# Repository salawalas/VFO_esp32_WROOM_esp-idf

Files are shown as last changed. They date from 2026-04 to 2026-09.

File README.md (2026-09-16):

# ESP32 VFO z generatorem Si5351A

Sterownik VFO zbudowany na ESP32-WROOM-32 i syntezerze Si5351A. Projekt generuje przestrajany sygnal w zakresie od 100 kHz do 225 MHz, pokazuje czestotliwosc na kolorowym wyswietlaczu TFT oraz udostepnia wygodna obsluge przez enkoder i piec przyciskow.

Repozytorium zawiera firmware ESP-IDF/PlatformIO oraz projekt PCB i schemat w KiCad.

## Najwazniejsze funkcje

- Zakres VFO: `100 kHz .. 225 MHz`.
- Syntezer Si5351A sterowany przez I2C 400 kHz.
- Wyjscia Si5351:
  - `CLK0` - glowny sygnal LO/VFO,
  - `CLK1` - nosna I,
  - `CLK2` - nosna Q, przesunieta wzgledem I.
- Kolorowy wyswietlacz ST7735 1.8", framebuffer `160 x 128 px`.
- Analogowa tarcza VFO oraz cyfrowy odczyt czestotliwosci.
- Enkoder kwadraturowy PCNT z dynamicznym przyspieszaniem strojenia.
- Kroki strojenia: `10 Hz`, `100 Hz`, `1 kHz`, `10 kHz`, `100 kHz`, `1 MHz`.
- Dziesiec komorek pamieci `M0..M9`.
- Autozapis ostatniej czestotliwosci do NVS po okresie bezczynnosci.
- Menu pasm z gotowymi czestotliwosciami startowymi.
- Blokada strojenia `LOCK`.
- Kalibracja czestotliwosci kwarcu Si5351 w zakresie `-5000..+5000 Hz`.
- Regulacja jasnosci podswietlenia PWM.
- Oddzielne srodowiska PlatformIO: `esp32_release` i `esp32_debug`.

## Sprzet

Glownymi elementami ukladu sa:

- ESP32-WROOM-32,
- modul Si5351A,
- wyswietlacz TFT 1.8" ze sterownikiem ST7735,
- enkoder obrotowy z przyciskiem,
- 5 przyciskow tact switch,
- podswietlenie wyswietlacza sterowane PWM,
- plytka PCB zaprojektowana w KiCad.

Pliki KiCad sa w katalogu `Kicad files/`.

## Polaczenia GPIO

| Funkcja | GPIO |
| --- | ---: |
| Enkoder A | 17 |
| Enkoder B | 16 |
| Przycisk enkodera SW | 34 |
| STEP_DN | 26 |
| STEP_UP | 27 |
| MEM | 25 |
| SAVE | 32 |
| BAND | 33 |
| Si5351 SDA | 21 |
| Si5351 SCL | 22 |
| ST7735 SCLK | 18 |
| ST7735 MOSI | 23 |
| ST7735 CS | 5 |
| ST7735 DC | 2 |
| ST7735 RST | 15 |
| Podswietlenie TFT | 4 |

Przyciski sa aktywne stanem niskim. W tej konstrukcji zewnetrzne rezystory pull-up sa wymagane dla GPIO16, GPIO17, GPIO33 i GPIO34. Na plytce zastosowano 4.7 kOhm, ale praktyczny zakres to ok. 2.2 kOhm .. 10 kOhm.

## Ekran

Normalny widok VFO pokazuje:

- analogowa tarcze strojenia,
- cyfrowa czestotliwosc generowana,
- aktywny krok strojenia,
- aktywny bank pamieci `VFO` albo `M1..M9`,
- graficzne overlaye dla operacji `SAVE`, `LOAD`, `LOCK`, menu pasm, jasnosci i kalibracji.

W trybie `LOCK` czestotliwosc pozostaje widoczna, a na ekranie pojawia sie duzy symbol klodki oraz napis `LOCK` na dole.

## Obsluga

### Enkoder

| Akcja | Efekt |
| --- | --- |
| Obrot w trybie VFO | Zmiana czestotliwosci wedlug aktywnego kroku |
| Szybki obrot | Automatyczne przyspieszenie strojenia `x10`, `x100`, `x1000` |
| Krotkie nacisniecie SW | Otwarcie menu pasm lub zatwierdzenie wyboru pasma |
| Dlugie nacisniecie SW | Zmiana kierunku pracy enkodera |
| Obrot w menu BAND | Przewijanie listy pasm |
| Obrot w XTAL CAL | Zmiana korekty kwarcu |
| Obrot w BRIGHTNESS | Zmiana jasnosci podswietlenia |

### Przyciski

| Przycisk | Krotkie nacisniecie | Dlugie nacisniecie |
| --- | --- | --- |
| STEP_DN | Mniejszy krok strojenia | - |
| STEP_UP | Wiekszy krok strojenia | - |
| MEM | Nastepny bank pamieci / YES w dialogu / SAVE w ekranach ustawien | Wczytanie czestotliwosci z aktywnego banku |
| SAVE | NO/CANCEL w dialogach | Otwarcie dialogu zapisu do aktywnego banku |
| BAND | Ekran regulacji jasnosci | Kalibracja kwarcu XTAL |
| STEP_DN + STEP_UP | `LOCK` po przytrzymaniu ok. 1 s | `LOCK` po przytrzymaniu ok. 1 s |

W trybie `LOCK` zmiana czestotliwosci i kroku jest blokowana. Odblokowanie odbywa sie ta sama kombinacja `STEP_DN + STEP_UP`.

## Pamiec i pasma

Firmware przechowuje parametry w NVS:

- ostatnia czestotliwosc,
- 10 komorek pamieci `M0..M9`,
- ostatni krok strojenia,
- korekta kwarcu Si5351,
- jasnosc wyswietlacza,
- ostatnio uzywany bank.

Domyslne komorki pamieci:

| Bank | Czestotliwosc |
| --- | ---: |
| M0 | 14.230 MHz |
| M1 | 3.730 MHz |
| M2 | 3.8531 MHz |
| M3 | 5.450 MHz |
| M4 | 5.505 MHz |
| M5 | 6.070 MHz |
| M6 | 7.130 MHz |
| M7 | 7.8781 MHz |
| M8 | 8.957 MHz |
| M9 | 10.100 MHz |

Menu pasm zawiera:

`30m`, `20m`, `17m`, `15m`, `12m`, `10m`, `6m` oraz `FM 100 MHz`.

## Tryby ekranowe

- `VFO` - normalna praca i strojenie.
- `SAVE TO Mx?` - potwierdzenie zapisu aktualnej czestotliwosci do pamieci.
- `SAVED` - komunikat po zapisie.
- `LOAD` - komunikat po wczytaniu pamieci.
- `SELECT BAND` - wybor pasma lub preset FM.
- `BRIGHTNESS` - regulacja jasnosci podswietlenia.
- `XTAL CALIBRATION` - korekta czestotliwosci referencyjnej Si5351.
- `LOCK` - blokada przypadkowej zmiany czestotliwosci.

## Budowanie

Projekt jest przygotowany pod PlatformIO z frameworkiem ESP-IDF.

Domyslnym srodowiskiem jest release:

```powershell
pio run
```

Jawny build release:

```powershell
pio run -e esp32_release
```

Build debug:

```powershell
pio run -e esp32_debug
```

Wgrywanie:

```powershell
pio run -e esp32_release -t upload
```

Monitor portu szeregowego:

```powershell
pio device monitor
```

Domyslny port uploadu w `platformio.ini` to `COM42`.

## Konfiguracja buildow

`platformio.ini` definiuje dwa warianty:

- `esp32_release` - normalny build firmware,
- `esp32_debug` - build debug z wyzszym poziomem logow.

Wspolne ustawienia ESP-IDF sa w `sdkconfig.defaults`. Dodatkowe ustawienia debug sa w `sdkconfig.debug.defaults`. Pelne pliki `sdkconfig.esp32_*` sa generowane przez PlatformIO lokalnie i sa ignorowane przez git.

## Struktura projektu

| Sciezka | Opis |
| --- | --- |
| `src/main.c` | Inicjalizacja systemu, zadanie wyswietlacza |
| `src/si5351.c` | Sterownik i obliczenia rejestrow Si5351 |
| `src/display.c` | Sterownik ST7735 i transfer DMA |
| `src/graph.c` | Framebuffer RGB i prymitywy graficzne |
| `src/dial.c` | Analogowa tarcza VFO |
| `src/encoder.c` | Obsluga enkodera PCNT |
| `src/buttons.c` | Obsluga przyciskow i trybow |
| `src/nvs_storage.c` | Pamiec NVS i autozapis |
| `src/ui_overlay.c` | Overlaye graficzne i menu |
| `include/config.h` | Glowne stale konfiguracyjne |
| `Kicad files/` | Projekt PCB i schemat |

## Uwagi

Projekt jest przeznaczony do pracy jako eksperymentalny generator/VFO. Przy podlaczaniu do torow radiowych nalezy zadbac o odpowiednie poziomy sygnalu, filtracje harmonicznych, ekranowanie i zgodnosc z lokalnymi przepisami dotyczacymi emisji radiowych.

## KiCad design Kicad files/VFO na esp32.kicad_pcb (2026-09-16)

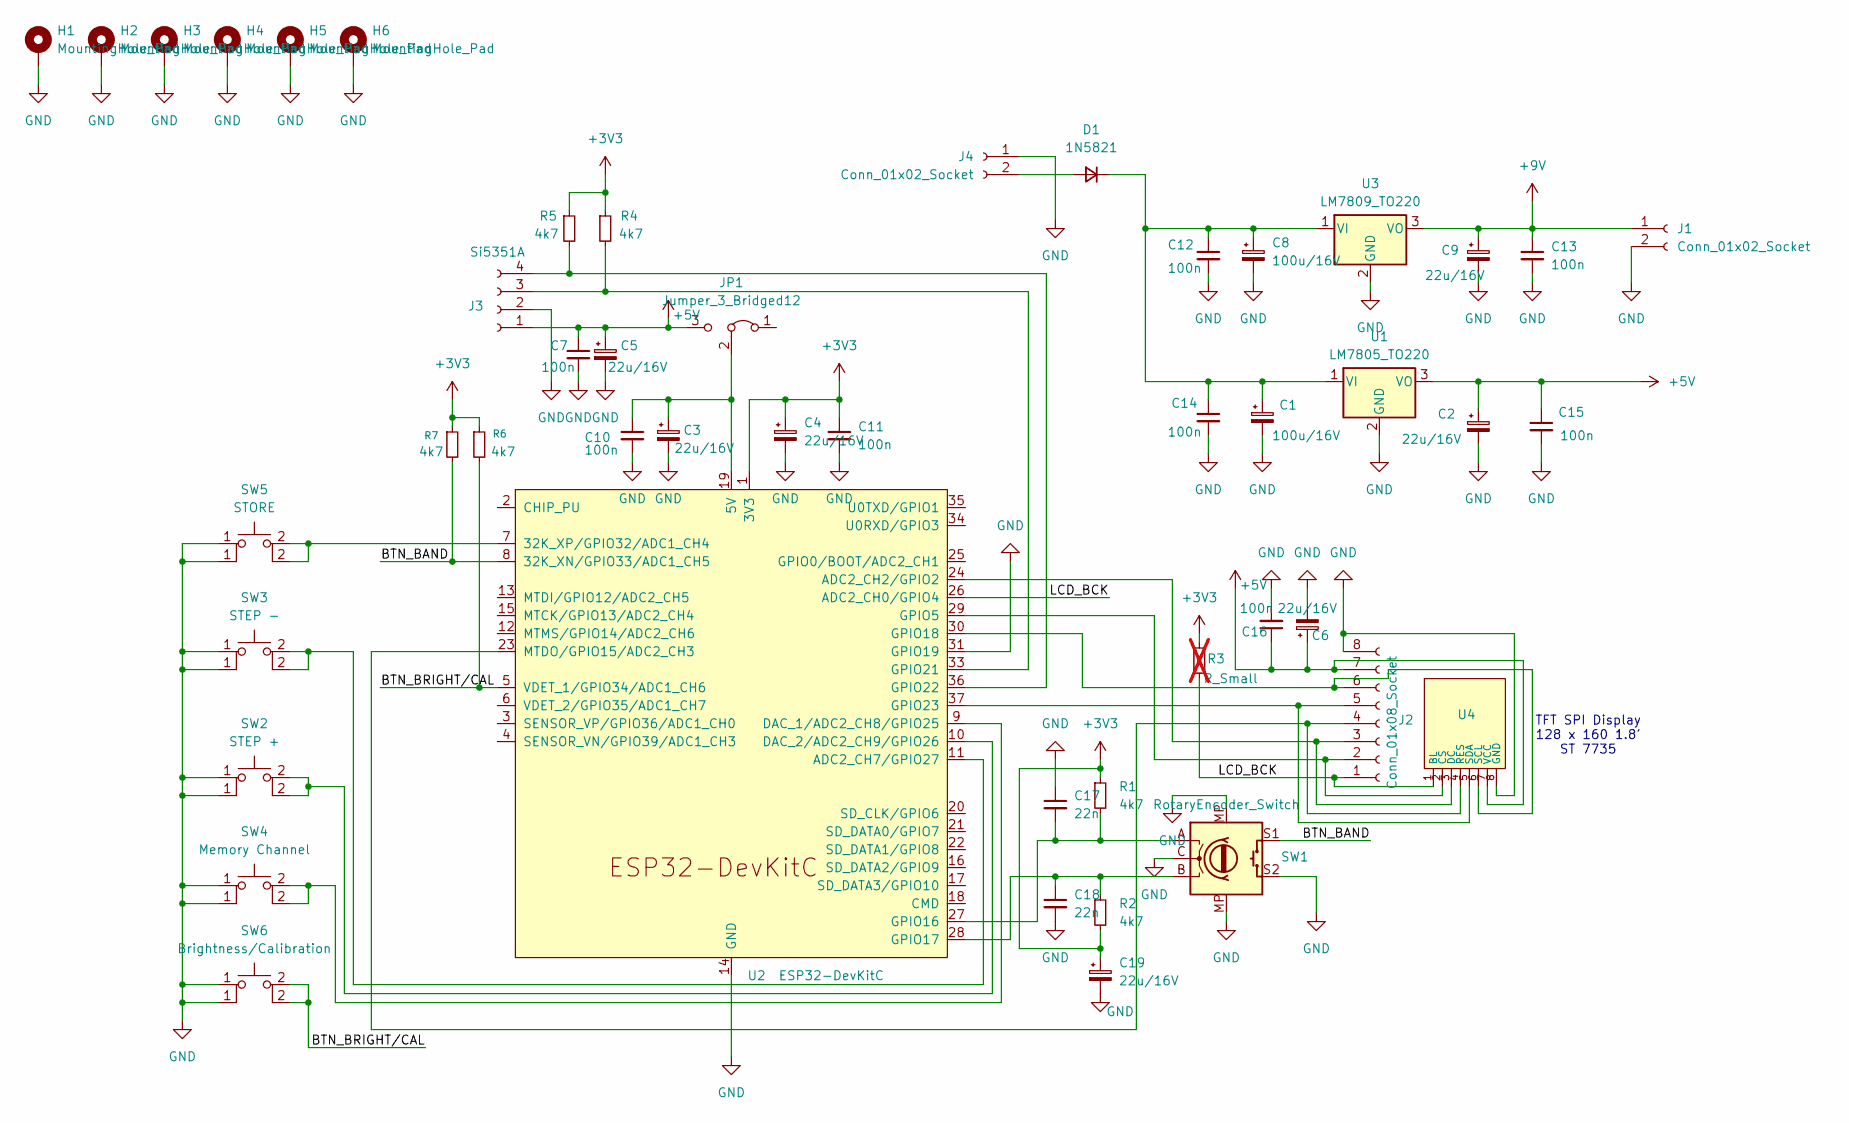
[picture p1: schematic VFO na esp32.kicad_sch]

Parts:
C1, C8: 100u/16V; CP_Radial_D8.0mm_P3.50mm
C2, C3, C4, C5, C6, C9, C19: 22u/16V; CP_Radial_Tantal_D5.0mm_P5.00mm
C7, C10, C11, C12, C13, C14, C15, C16: 100n; C_0805_2012Metric_Pad1.18x1.45mm_HandSolder
C17, C18: 22n; C_Axial_L5.1mm_D3.1mm_P10.00mm_Horizontal
D1: 1N5821; D_DO-15_P10.16mm_Horizontal
H1, H2, H3, H4, H5, H6: MountingHole_Pad; MountingHole_2.7mm_M2.5_DIN965_Pad_TopBottom
J1, J4: Conn_01x02_Socket; JST_EH_S2B-EH_1x02_P2.50mm_Horizontal
J2: Conn_01x08_Socket; PinSocket_1x08_P2.54mm_Vertical
J3: Si5351A; JST_PH_B4B-PH-K_1x04_P2.00mm_Vertical
JP1: Jumper_3_Bridged12; PinHeader_1x03_P2.54mm_Vertical
R1, R2: 4k7; R_Axial_DIN0207_L6.3mm_D2.5mm_P10.16mm_Horizontal
R3: R_Small; R_Axial_DIN0207_L6.3mm_D2.5mm_P10.16mm_Horizontal; not fitted
R4, R5: 4k7; R_0805_2012Metric_Pad1.20x1.40mm_HandSolder
R6, R7: 4k7; R_1206_3216Metric
SW1: RotaryEncoder_Switch; RotaryEncoder_Alps_EC11E-Switch_Vertical_H20mm
SW2: STEP +; SW_PUSH_6mm_H5mm
SW3: STEP -; SW_PUSH_6mm_H5mm
SW4: Memory Channel; SW_PUSH_6mm_H5mm
SW5: STORE; SW_PUSH_6mm_H5mm
SW6: Brightness/Calibration; SW_PUSH_6mm_H5mm
U1: LM7805_TO220; TO-220F-3_Horizontal_TabDown
U2: ESP32-DevKitC
U3: LM7809_TO220; TO-220F-3_Horizontal_TabDown
U4: TFT_SPI_1.8inch_128x160

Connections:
+3V3: C4.1, C11.1, C19.1, R1.1, R2.2, R3.2, R4.1, R5.1, R6.1, R7.1, U2.1 (3V3)
+5V: C2.1, C5.1, C6.1, C7.1, C15.1, C16.1, J2.7, J3.1, JP1.3 (B), U1.3 (VO), U4.7 (VCC)
+9V: C9.1, C13.1, J1.1, U3.3 (VO)
/BTN_BAND: R7.2, SW1.S1, U2.8 (32K_XN/GPIO33/ADC1_CH5)
/BTN_BRIGHT/CAL: R6.2, SW6.2, U2.5 (VDET_1/GPIO34/ADC1_CH6)
/LCD_BCK: J2.1, R3.1, U2.26 (ADC2_CH0/GPIO4), U4.1 (BL)
GND: C1.2, C2.2, C3.2, C4.2, C5.2, C6.2, C7.2, C8.2, C9.2, C10.2, C11.2, C12.2, C13.2, C14.2, C15.2, C16.2, C17.1, C18.2, C19.2, H1.1 (1_1), H2.1 (1_1), H3.1 (1_1), H4.1 (1_1), H5.1 (1_1), H6.1 (1_1), J1.2, J2.8, J3.2, J4.1, SW1.C, SW1.MP, SW1.S2, SW2.1, SW3.1, SW4.1, SW5.1, SW6.1, U1.2 (GND), U2.14 (GND), U2.31 (GPIO19), U2.32 (GND), U2.38 (GND), U3.2 (GND), U4.8 (GND)
unnamed: D1.2 (A), J4.2
unnamed: C1.1, C8.1, C12.1, C14.1, D1.1 (K), U1.1 (VI), U3.1 (VI)
unnamed: J2.2, U2.29 (GPIO5), U4.2 (CS)
unnamed: J2.3, U2.24 (ADC2_CH2/GPIO2), U4.3 (DC)
unnamed: J2.4, U2.23 (MTDO/GPIO15/ADC2_CH3), U4.4 (RES)
unnamed: J2.5, U2.37 (GPIO23), U4.5 (SDA)
unnamed: J2.6, U2.30 (GPIO18), U4.6 (SCL)
unnamed: J3.3, R4.2, U2.33 (GPIO21)
unnamed: J3.4, R5.2, U2.36 (GPIO22)
unnamed: C3.1, C10.1, JP1.2 (C), U2.19 (5V)
unnamed: SW5.2, U2.7 (32K_XP/GPIO32/ADC1_CH4)
unnamed: SW3.2, U2.11 (ADC2_CH7/GPIO27)
unnamed: SW4.2, U2.9 (DAC_1/ADC2_CH8/GPIO25)
unnamed: SW2.2, U2.10 (DAC_2/ADC2_CH9/GPIO26)
unnamed: C17.2, R1.2, SW1.A, U2.27 (GPIO16)
unnamed: C18.1, R2.1, SW1.B, U2.28 (GPIO17)

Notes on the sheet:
TFT SPI Display 128 x 160 1.8' ST 7735

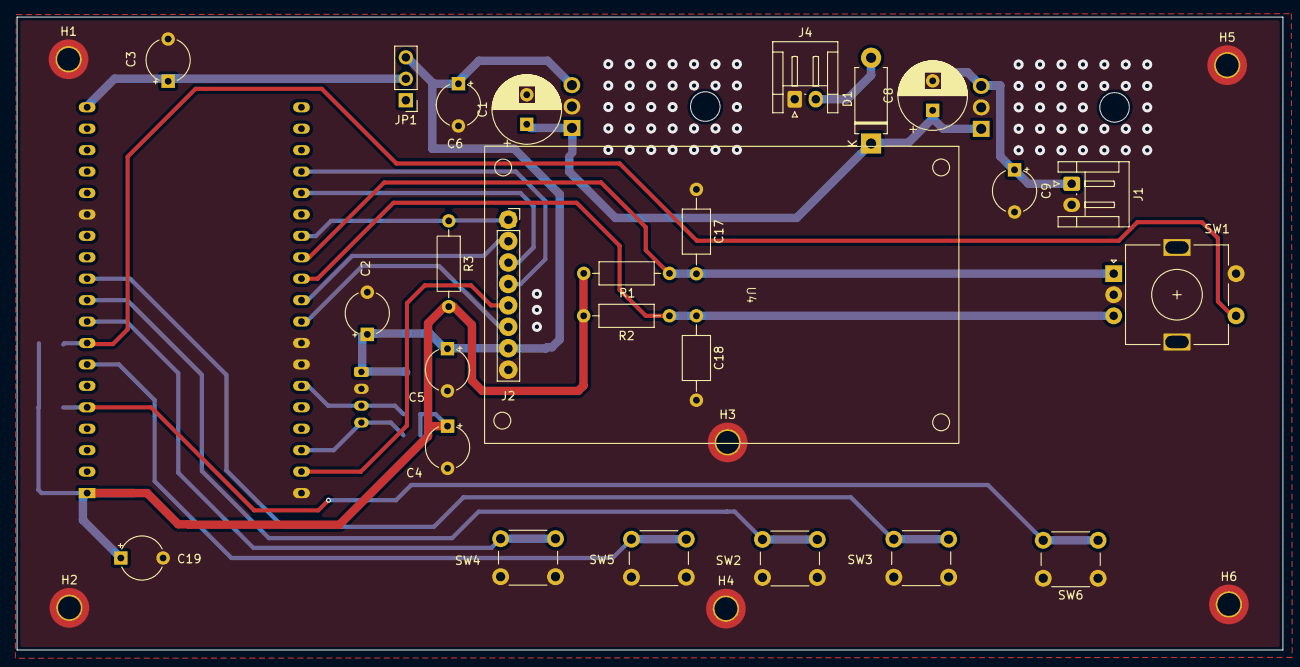
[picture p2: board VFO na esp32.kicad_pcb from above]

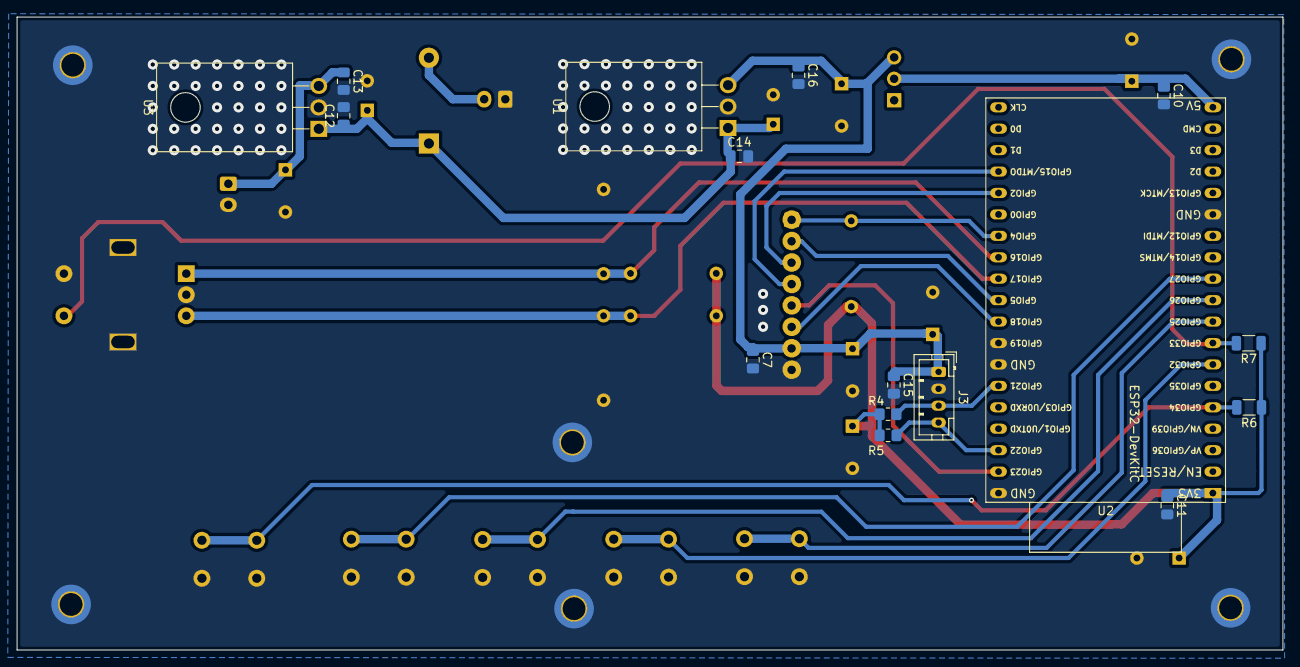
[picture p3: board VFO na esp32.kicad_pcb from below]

Board: 2 copper layers, 150.0 x 75.0 mm, 48 parts (16 on the bottom side), 23 nets.

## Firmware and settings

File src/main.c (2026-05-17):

/*===========================================================================
 *  main.c — VFO Controller (ESP-IDF 5.x / PlatformIO)
 *===========================================================================*/
#include <stdio.h>
#include <string.h>

#include "freertos/FreeRTOS.h"
#include "freertos/task.h"
#include "freertos/semphr.h"

#include "esp_log.h"
#include "esp_err.h"
#include "nvs_flash.h"
#include "driver/ledc.h"

#include "config.h"
#include "vfo_state.h"
#include "si5351.h"
#include "display.h"
#include "graph.h"
#include "dial.h"
#include "encoder.h"
#include "buttons.h"
#include "nvs_storage.h"
#include "ui_overlay.h"
#include "version.h"
#include "esp_system.h"
#include "esp_chip_info.h"
#include "esp_flash.h"

static void display_task(void *arg);
static void system_init(void);
static void tasks_start(void);
static void backlight_init(uint8_t pct);

/*===========================================================================
 *  app_main
 *===========================================================================*/
void app_main(void)
{
    ESP_LOGI(TAG_MAIN, "============================================");
    //ESP_LOGI(TAG_MAIN, "  %s  %s", FW_NAME, FW_VERSION);
    //ESP_LOGI(TAG_MAIN, "  %s", FW_AUTHOR);
    //ESP_LOGI(TAG_MAIN, "============================================");

    ESP_LOGI(TAG_MAIN, "%s %s", FW_NAME, FW_VERSION);
    ESP_LOGI(TAG_MAIN, "%s", FW_AUTHOR);
    ESP_LOGI(TAG_MAIN, "%s", BUILD_DATE);
    ESP_LOGI(TAG_MAIN, "commit %s", FW_COMMIT);
    ESP_LOGI(TAG_MAIN, "============================================");

    /* NVS flash init */
    esp_err_t ret = nvs_flash_init();
    if (ret == ESP_ERR_NVS_NO_FREE_PAGES ||
        ret == ESP_ERR_NVS_NEW_VERSION_FOUND) {
        ESP_LOGW(TAG_MAIN, "NVS: czyszczenie i reinicjalizacja...");
        ESP_ERROR_CHECK(nvs_flash_erase());
        ret = nvs_flash_init();
    }
    ESP_ERROR_CHECK(ret);
    ESP_LOGI(TAG_MAIN, "NVS flash: OK");

    vfo_state_init();
    ESP_LOGI(TAG_MAIN, "Globalny stan VFO: OK");

    system_init();
    tasks_start();

    ESP_LOGI(TAG_MAIN, "Scheduler uruchomiony.");

    esp_chip_info_t chip;
    esp_chip_info(&chip);

    uint32_t flash_size;
    esp_flash_get_size(NULL, &flash_size);

    ESP_LOGI("CHIP", "Model: ESP32 rev %d", chip.revision);
    ESP_LOGI("CHIP", "Rdzenie CPU: %d", chip.cores);
    ESP_LOGI("CHIP", "Flash: %lu MB", (unsigned long)(flash_size / (1024*1024)));
    ESP_LOGI("CHIP", "WiFi: %s  BT: %s  BLE: %s",
        (chip.features & CHIP_FEATURE_WIFI_BGN) ? "TAK" : "NIE",
        (chip.features & CHIP_FEATURE_BT)       ? "TAK" : "NIE",
        (chip.features & CHIP_FEATURE_BLE)      ? "TAK" : "NIE");
    ESP_LOGI("CHIP", "RAM: ~520 KB SRAM (standard ESP32)");

    vTaskDelete(NULL);
}

/*===========================================================================
 *  system_init
 *===========================================================================*/
static void system_init(void)
{
    esp_err_t err;

    err = nvs_storage_init();
    if (err == ESP_OK) {
        uint32_t saved_freq = 0;
        if (nvs_load_last_freq(&saved_freq) == ESP_OK && saved_freq != 0) {
            VFO_LOCK();
            g_vfo.freq = saved_freq;
            ESP_LOGI(TAG_MAIN, "Wczytano czestotliwosc: %lu Hz",
                     (unsigned long)saved_freq);
            VFO_UNLOCK();
        }
        for (int i = 0; i < VFO_MEM_COUNT; i++) {
            uint32_t mf = 0;
            if (nvs_load_mem(i, &mf) == ESP_OK && mf != 0) {
                VFO_LOCK();
                g_vfo.mem_freq[i] = mf;
                VFO_UNLOCK();
            }
        }
        /* Pozostale parametry z NVS */
        int      step_idx = FREQ_STEP_DEFAULT;
        int32_t  xtal_cal = 0, if_off = 0, rit_off = 0;
        uint8_t  bright   = BRIGHTNESS_DEFAULT;
        int      last_mem = 0;

        if (nvs_load_step_idx(&step_idx) == ESP_OK) {
            if (step_idx < 0) step_idx = 0;
            if (step_idx >= FREQ_STEP_COUNT) step_idx = FREQ_STEP_COUNT - 1;
        }
        nvs_load_xtal_cal(&xtal_cal);
        nvs_load_if_offset(&if_off);
        nvs_load_brightness(&bright);
        if (bright < BRIGHTNESS_MIN || bright > BRIGHTNESS_MAX)
            bright = BRIGHTNESS_DEFAULT;
        nvs_load_last_mem(&last_mem);
        nvs_load_rit(&rit_off);

        VFO_LOCK();
        g_vfo.step_idx    = step_idx;
        g_vfo.xtal_cal    = xtal_cal;
        g_vfo.if_offset   = if_off;
        g_vfo.brightness  = bright;
        g_vfo.last_mem_idx = last_mem;
        g_vfo.rit_offset  = rit_off;
        VFO_UNLOCK();
    }

    /* Podswietlenie PWM */
    VFO_LOCK();
    uint8_t bright = g_vfo.brightness;
    VFO_UNLOCK();
    backlight_init(bright);
    ESP_LOGI(TAG_MAIN, "Podswietlenie LEDC: OK (%d%%)", (int)bright);

    err = si5351_init();
    ESP_ERROR_CHECK(err);
    VFO_LOCK();
    int32_t cal = g_vfo.xtal_cal;
    VFO_UNLOCK();
    if (cal != 0) si5351_set_xtal_cal(cal);
    ESP_LOGI(TAG_MAIN, "Si5351A: OK");

    err = display_init();
    ESP_ERROR_CHECK(err);
    ESP_LOGI(TAG_MAIN, "Wyswietlacz ST7735: OK");

    dial_init();

    err = encoder_init();
    ESP_ERROR_CHECK(err);
    ESP_LOGI(TAG_MAIN, "Enkoder PCNT: OK");

    err = buttons_init();
    ESP_ERROR_CHECK(err);
    ESP_LOGI(TAG_MAIN, "Przyciski GPIO: OK");



    /* Splash screen */
    {
        char spl[48];
        gram_clear();

        /* Naglowek z ramka */
        boxfill(2, 108, NX - 3, NY - 2, 0x001a2a);
        draw_box(2, 108, NX - 3, NY - 2, 0x0066aa);
        disp_str16(FW_NAME, 22, 110, 0x00ccff);

        /* Separator 1 */
        draw_line(4, 106, NX - 5, 106, 0x224466);

        /* Wersja + commit hash w dwoch wierszach */
        disp_str8("ver", 4, 95, 0x778899);
        disp_str12(FW_VERSION, 30, 92, 0xffd080);
        disp_str8("git", 4, 81, 0x778899);
        snprintf(spl, sizeof(spl), "%s", FW_COMMIT);
        disp_str12(spl, 30, 78, 0xff8833);

        /* Data buildu */
        disp_str8(BUILD_DATE, 4, 68, 0x99aabb);

        /* Separator 2 */
        draw_line(4, 64, NX - 5, 64, 0x224433);

        /* Heap */
        uint32_t heap_kb = esp_get_free_heap_size() / 1024;
        disp_str8("Heap", 4, 52, 0x55aa55);
        snprintf(spl, sizeof(spl), "%lu KB free", (unsigned long)heap_kb);
        disp_str12(spl, 38, 49, 0x66ff66);

        /* CPU freq */
        disp_str8("CPU", 4, 36, 0x55aa55);
        snprintf(spl, sizeof(spl), "%d MHz", CONFIG_ESP32_DEFAULT_CPU_FREQ_MHZ);
        disp_str12(spl, 38, 33, 0x66ff66);

        /* IDF version */
        disp_str8("IDF", 4, 20, 0x55aa55);
        disp_str12(esp_get_idf_version(), 38, 18, 0x88ddaa);

        /* Separator 3 */
        draw_line(4, 13, NX - 5, 13, 0x1a2a1a);

        /* Autor + sprzet */
        disp_str8(FW_AUTHOR, 4, 2, 0x6699bb);
        disp_str8("ST7735 Si5351A", 70, 2, 0x6699bb);

        display_trans65k();
        display_transfer_image();
        vTaskDelay(pdMS_TO_TICKS(5000));
    }

    /* Po splashu — wyczysc ekran i ustaw flagi dla display_task */
    gram_clear();
    display_trans65k();
    display_transfer_image();

    VFO_LOCK();
    g_vfo.f_freq_changed = true;
    g_vfo.f_disp_changed = true;  /* display_task odrysuje po starcie */
    VFO_UNLOCK();

    ESP_LOGI(TAG_MAIN, "system_init: KOMPLETNA");
}

/*===========================================================================
 *  tasks_start
 *===========================================================================*/
static void tasks_start(void)
{
    BaseType_t res;

    res = xTaskCreatePinnedToCore(encoder_task, "encoder",
            TASK_ENCODER_STACK, NULL, TASK_ENCODER_PRIO, NULL, TASK_ENCODER_CORE);
    configASSERT(res == pdPASS);

    res = xTaskCreatePinnedToCore(display_task, "display",
            TASK_DISPLAY_STACK, NULL, TASK_DISPLAY_PRIO, NULL, TASK_DISPLAY_CORE);
    configASSERT(res == pdPASS);

    res = xTaskCreatePinnedToCore(buttons_task, "buttons",
            TASK_BUTTONS_STACK, NULL, TASK_BUTTONS_PRIO, NULL, TASK_BUTTONS_CORE);
    configASSERT(res == pdPASS);

    res = xTaskCreatePinnedToCore(autosave_task, "autosave",
            TASK_AUTOSAVE_STACK, NULL, TASK_AUTOSAVE_PRIO, NULL, TASK_AUTOSAVE_CORE);
    configASSERT(res == pdPASS);

    ESP_LOGI(TAG_MAIN, "Wszystkie taski uruchomione.");
}

/*===========================================================================
 *  display_task — Core 0
 *===========================================================================*/
static void display_task(void *arg)
{
    (void)arg;
    char str[64];

    ESP_LOGI(TAG_MAIN, "display_task: start");

    while (1) {
        VFO_LOCK();
        bool        f_disp   = g_vfo.f_disp_changed;
        bool        f_freq   = g_vfo.f_freq_changed;
        uint32_t    freq     = g_vfo.freq;
        bool        car_on   = g_vfo.car_on;
        int         step_idx = g_vfo.step_idx;
        int         mem_idx  = g_vfo.mem_idx;
        bool        locked   = g_vfo.locked;
        disp_mode_t mode     = g_vfo.disp_mode;
        int         band_sel = g_vfo.band_sel;
        int32_t     xtal_cal = g_vfo.xtal_cal;
        if (f_disp) g_vfo.f_disp_changed = false;
        if (f_freq) g_vfo.f_freq_changed  = false;
        VFO_UNLOCK();

        if (f_freq) {
            si5351_set_xtal_cal(xtal_cal);   /* aktualizuj kalibracje przed synteza */
            si5351_set_freq(freq);
            si5351_set_car_freq(freq, car_on);
        }

        if (f_disp) {
            if (mode == DISP_MODE_BAND_MENU) {
                /* Pelnoekranowe menu — pomija dial_draw */
                ui_draw_band_menu(band_sel);

            } else if (mode == DISP_MODE_XTAL_CAL) {
                /* Pelnoekranowy ekran kalibracji — pomija dial_draw */
                ui_draw_xtal_cal(xtal_cal);

            } else if (mode == DISP_MODE_BRIGHTNESS) {
                /* Pelnoekranowy ekran regulacji jasnosci */
                VFO_LOCK();
                uint8_t br = g_vfo.brightness;
                VFO_UNLOCK();
                ui_draw_brightness(br);

            } else {
                /* Normalny widok VFO + overlaye */
                boxfill(0, 0, NX - 1, NY - 1, 0x000000);
                dial_draw(freq);
                draw_box(7, 100, 153, 126, 0xa0a0a0);
                draw_box(6,  99, 154, 127, 0xa0a0a0);

                /* Krok */
                const char *step_labels[] = {
                    "STEPS 10 Hz", "STEPS 100 Hz", "STEPS 1 kHz",
                    "STEPS 10 kHz", "STEPS 100 kHz", "STEPS 1 MHz"
                };
                if (step_idx >= 0 && step_idx < FREQ_STEP_COUNT) {
                    disp_str8(step_labels[step_idx], 50, 85, 0xffd080);
                }

                /* Bank pamięci */
                if (mem_idx == 0) {
                    disp_str8("VFO", 5, 85, 0x00ffff);
                } else {
                    snprintf(str, sizeof(str), "M%d", mem_idx);
                    disp_str8(str, 5, 85, 0xffd080);
                }

                /* Częstotliwość cyfrowa */
                snprintf(str, sizeof(str), "%3lu.%03lu,%02lu",
                    (unsigned long)(freq / 1000000UL),
                    (unsigned long)((freq / 1000UL) % 1000UL),
                    (unsigned long)((freq / 10UL)   % 100UL));
                disp_str16(str, 17, 105, 0xffd080);
                disp_str12("MHz", 120, 106, 0xffd080);

                /* LOCK — napis na dole ekranu */
                ui_draw_lock_icon(locked);

                /* Overlaye na tarczy */
                if (mode == DISP_MODE_SAVE_OK) {
                    ui_draw_saved_confirm(mem_idx, freq);
                } else if (mode == DISP_MODE_LOAD_OK) {
                    ui_draw_loaded_confirm(mem_idx, freq);
                } else if (mode == DISP_MODE_SAVE_PROMPT) {
                    ui_draw_save_prompt(mem_idx);
                }
            }

            display_trans65k();
            display_transfer_image();
        }

        vTaskDelay(pdMS_TO_TICKS(10));
    }
}

/*===========================================================================
 *  backlight_init / backlight_set — PWM podswietlenia (LEDC)
 *===========================================================================*/
static void backlight_init(uint8_t pct)
{
    ledc_timer_config_t timer = {
        .speed_mode      = LEDC_LOW_SPEED_MODE,
        .timer_num       = LEDC_TIMER_BL,
        .duty_resolution = LEDC_TIMER_8_BIT,
        .freq_hz         = LEDC_FREQ_BL,
        .clk_cfg         = LEDC_AUTO_CLK,
    };
    ledc_timer_config(&timer);

    ledc_channel_config_t ch = {
        .gpio_num   = DISP_BL,
        .speed_mode = LEDC_LOW_SPEED_MODE,
        .channel    = LEDC_CHANNEL_BL,
        .timer_sel  = LEDC_TIMER_BL,
        .duty       = 0,
        .hpoint     = 0,
    };
    ledc_channel_config(&ch);

    /* Ustaw poczatkowe wypelnienie */
    uint32_t duty = (uint32_t)pct * 255 / 100;
    ledc_set_duty(LEDC_LOW_SPEED_MODE, LEDC_CHANNEL_BL, duty);
    ledc_update_duty(LEDC_LOW_SPEED_MODE, LEDC_CHANNEL_BL);
}

void backlight_set(uint8_t pct)
{
    if (pct > BRIGHTNESS_MAX) pct = BRIGHTNESS_MAX;
    if (pct < BRIGHTNESS_MIN) pct = BRIGHTNESS_MIN;
    uint32_t duty = (uint32_t)pct * 255 / 100;
    ledc_set_duty(LEDC_LOW_SPEED_MODE, LEDC_CHANNEL_BL, duty);
    ledc_update_duty(LEDC_LOW_SPEED_MODE, LEDC_CHANNEL_BL);
}

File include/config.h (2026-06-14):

/*===========================================================================
 *  config.h — VFO Controller (ESP-IDF 5.x / PlatformIO)
 *===========================================================================*/
#pragma once

#include <stdint.h>
#include "esp_err.h"

/*---------------------------------------------------------------------------
 *  GPIO — Enkoder obrotowy
 *--------------------------------------------------------------------------*/
#define ENC_PIN_A       17
#define ENC_PIN_B       16

/*---------------------------------------------------------------------------
 *  GPIO — Przyciski (active LOW, INPUT_PULLUP)
 *--------------------------------------------------------------------------*/
#define BTN_STEP_DN     26
#define BTN_STEP_UP     27
#define BTN_MEM         25
#define BTN_SAVE        32
#define BTN_BAND        33      /* 5. przycisk — wybor pasma, GPIO z pull-up */

/*---------------------------------------------------------------------------
 *  GPIO — Si5351A (hardware I2C)
 *--------------------------------------------------------------------------*/
#define SI5351_SDA          21
#define SI5351_SCL          22
#define SI5351_I2C_ADDR     0x60
#define SI5351_I2C_FREQ     400000
#define SI5351_XTAL_FREQ    24999250UL

/*---------------------------------------------------------------------------
 *  GPIO — Wyswietlacz ST7735 128x160 (SPI)
 *--------------------------------------------------------------------------*/
#define DISP_SCLK       18
#define DISP_MOSI       23
#define DISP_CS          5
#define DISP_DC          2
#define DISP_RST        15
#define DISP_SPI_FREQ   27000000

/*---------------------------------------------------------------------------
 *  Wymiary wyswietlacza
 *--------------------------------------------------------------------------*/

/*---------------------------------------------------------------------------
 *  Czestotliwosci VFO
 *--------------------------------------------------------------------------*/
#define VFO_FREQ_INIT   14230000UL
#define VFO_FREQ_MAX    225000000UL
#define VFO_FREQ_MIN       100000UL

/*---------------------------------------------------------------------------
 *  Si5351 CLK outputs
 *--------------------------------------------------------------------------*/
#define SI5351_CLK_LO    0   /* CLK0 = LO (VFO, PLL_A) */
#define SI5351_CLK_CAR_I 1   /* CLK1 = nosna glowna I (PLL_B, 0 deg) */
#define SI5351_CLK_CAR_Q 2   /* CLK2 = nosna Q (PLL_B, 90 deg, INV) */

/*---------------------------------------------------------------------------
 *  Kroki czestotliwosci — makra zamiast tablic (zero problemow z ODR)
 *--------------------------------------------------------------------------*/
#define FREQ_STEP_COUNT   6
#define FREQ_STEP_DEFAULT 2

#define FREQ_STEP_0       10
#define FREQ_STEP_1       100
#define FREQ_STEP_2       1000
#define FREQ_STEP_3       10000
#define FREQ_STEP_4       100000
#define FREQ_STEP_5       1000000

/* Tablica krokow — dostepna w runtime (static = jedna kopia na TU) */
static const int32_t FREQ_STEPS[FREQ_STEP_COUNT] = {
    FREQ_STEP_0, FREQ_STEP_1, FREQ_STEP_2,
    FREQ_STEP_3, FREQ_STEP_4, FREQ_STEP_5
};

/*---------------------------------------------------------------------------
 *  Pamiec VFO
 *--------------------------------------------------------------------------*/
#define VFO_MEM_COUNT   10

#define VFO_MEM_0   14230000UL
#define VFO_MEM_1    3730000UL
#define VFO_MEM_2    3853100UL
#define VFO_MEM_3    5450000UL
#define VFO_MEM_4    5505000UL
#define VFO_MEM_5    6070000UL
#define VFO_MEM_6    7130000UL
#define VFO_MEM_7    7878100UL
#define VFO_MEM_8    8957000UL
#define VFO_MEM_9   10100000UL

/*---------------------------------------------------------------------------
 *  Dynamiczny enkoder
 *--------------------------------------------------------------------------*/
#define ENC_ACCEL_FAST_THR   5
#define ENC_ACCEL_VFAST_THR  15

/*---------------------------------------------------------------------------
 *  Przyciski — czasy [ms]
 *--------------------------------------------------------------------------*/
#define BTN_DEBOUNCE_MS      50
#define BTN_SHORT_MAX_MS    500
#define BTN_LONG_MIN_MS    1000
#define BTN_LOCK_HOLD_MS   1000

/*---------------------------------------------------------------------------
 *  NVS
 *--------------------------------------------------------------------------*/
#define NVS_NAMESPACE       "vfo"
#define NVS_KEY_LAST_FREQ   "last_frq"
#define NVS_KEY_MEM_PREFIX  "mem"

/*---------------------------------------------------------------------------
 *  Autozapis [ms]
 *--------------------------------------------------------------------------*/
#define AUTOSAVE_DELAY_MS   10000
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

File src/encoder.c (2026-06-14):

/*===========================================================================
 *  encoder.c — Enkoder obrotowy (PCNT v2, ESP-IDF 5.x)
 *
 *  PCNT v2 API (ESP-IDF >= 5.0):
 *    pcnt_new_unit()     zamiast pcnt_unit_config()
 *    pcnt_new_channel()  zamiast pcnt_channel_config()
 *    pcnt_unit_start()   zamiast pcnt_counter_resume()
 *
 *  Konfiguracja kanalow — identyczna z oryginaem Arduino:
 *    Kanal 0: pulse=A, ctrl=B, lctrl=REVERSE, hctrl=KEEP,  pos=INC, neg=DEC
 *    Kanal 1: pulse=B, ctrl=A, lctrl=KEEP,    hctrl=REVERSE,pos=INC, neg=DEC
 *    => 4x rozdzielczosc (quadrature x4)
 *
 *  Dynamiczny mnoznik kroku:
 *    Mierzony co ENC_TASK_PERIOD_MS (20ms).
 *    |impulsy| na cykl okreslaja mnoznik: x1 / x10 / x100 / x1000
 *    Mnoznik resetuje sie do x1 gdy enkoder stoi.
 *
 *  Przycisk SW enkodera:
 *    Krotkie nacisniecie: reset mnoznika do x1 (natychmiastowy powrot do slow)
 *    Dlugie nacisniecie: toggle kierunku f_rev
 *===========================================================================*/

#include "encoder.h"
#include "config.h"
#include "vfo_state.h"
#include "display.h"
#include "esp_log.h"
#include "driver/gpio.h"
#include "driver/pulse_cnt.h"
#include "freertos/FreeRTOS.h"
#include "freertos/task.h"

/*---------------------------------------------------------------------------
 *  Stale
 *--------------------------------------------------------------------------*/
#define ENC_TASK_PERIOD_MS  20      /* okres odczytu PCNT [ms]          */
#define ENC_GLITCH_NS       1000    /* filtr glitchy [ns]               */
#define ENC_COUNT_LIMIT     32767   /* limit licznika PCNT              */
#define ENC_SW_DEBOUNCE_MS  50      /* debouncing przycisku SW [ms]     */
#define ENC_SW_LONG_MS      800     /* prog dlugiego nacisniecia [ms]   */

/*---------------------------------------------------------------------------
 *  Zmienne modulowe
 *--------------------------------------------------------------------------*/
static pcnt_unit_handle_t   s_pcnt_unit = NULL;
static int                  s_accel_mul = 1;    /* aktualny mnoznik x1/10/100/1000 */

/*===========================================================================
 *  encoder_init — inicjalizacja PCNT v2
 *===========================================================================*/
esp_err_t encoder_init(void)
{
    esp_err_t err;

    /* --- Jednostka PCNT --- */
    pcnt_unit_config_t unit_cfg = {
        .low_limit  = -ENC_COUNT_LIMIT,
        .high_limit =  ENC_COUNT_LIMIT,
        .flags.accum_count = false,
    };
    err = pcnt_new_unit(&unit_cfg, &s_pcnt_unit);
    if (err != ESP_OK) {
        ESP_LOGE(TAG_ENC, "pcnt_new_unit: %s", esp_err_to_name(err));
        return err;
    }

    /* --- Filtr glitchy --- */
    pcnt_glitch_filter_config_t flt = {
        .max_glitch_ns = ENC_GLITCH_NS,
    };
    err = pcnt_unit_set_glitch_filter(s_pcnt_unit, &flt);
    if (err != ESP_OK) {
        ESP_LOGE(TAG_ENC, "glitch_filter: %s", esp_err_to_name(err));
        return err;
    }

    /* --- Kanal 0: pulse=A(17), ctrl=B(16) --- */
    pcnt_chan_config_t ch0_cfg = {
        .edge_gpio_num  = ENC_PIN_A,   /* GPIO17 */
        .level_gpio_num = ENC_PIN_B,   /* GPIO16 */
    };
    pcnt_channel_handle_t ch0 = NULL;
    err = pcnt_new_channel(s_pcnt_unit, &ch0_cfg, &ch0);
    if (err != ESP_OK) {
        ESP_LOGE(TAG_ENC, "pcnt_new_channel ch0: %s", esp_err_to_name(err));
        return err;
    }
    /* Zbocze narastajace: INC gdy ctrl=LOW(REVERSE), DEC gdy ctrl=HIGH(KEEP) */
    pcnt_channel_set_edge_action(ch0,
        PCNT_CHANNEL_EDGE_ACTION_INCREASE,   /* pos edge */
        PCNT_CHANNEL_EDGE_ACTION_DECREASE);  /* neg edge */
    pcnt_channel_set_level_action(ch0,
        PCNT_CHANNEL_LEVEL_ACTION_KEEP,      /* ctrl HIGH -> keep */
        PCNT_CHANNEL_LEVEL_ACTION_INVERSE);  /* ctrl LOW  -> reverse */

    /* --- Kanal 1: pulse=B(16), ctrl=A(17) --- */
    pcnt_chan_config_t ch1_cfg = {
        .edge_gpio_num  = ENC_PIN_B,   /* GPIO16 */
        .level_gpio_num = ENC_PIN_A,   /* GPIO17 */
    };
    pcnt_channel_handle_t ch1 = NULL;
    err = pcnt_new_channel(s_pcnt_unit, &ch1_cfg, &ch1);
    if (err != ESP_OK) {
        ESP_LOGE(TAG_ENC, "pcnt_new_channel ch1: %s", esp_err_to_name(err));
        return err;
    }
    pcnt_channel_set_edge_action(ch1,
        PCNT_CHANNEL_EDGE_ACTION_INCREASE,
        PCNT_CHANNEL_EDGE_ACTION_DECREASE);
    pcnt_channel_set_level_action(ch1,
        PCNT_CHANNEL_LEVEL_ACTION_INVERSE,   /* ctrl HIGH -> reverse */
        PCNT_CHANNEL_LEVEL_ACTION_KEEP);     /* ctrl LOW  -> keep    */

    /* --- Wlacz licznik --- */
    err = pcnt_unit_enable(s_pcnt_unit);
    if (err != ESP_OK) return err;
    err = pcnt_unit_clear_count(s_pcnt_unit);
    if (err != ESP_OK) return err;
    err = pcnt_unit_start(s_pcnt_unit);
    if (err != ESP_OK) return err;

    /* --- GPIO dla przycisku SW enkodera ---
     * ENC_PIN_SW=34 jest input-only — nie mozna ustawic pull-up programowo.
     * Wymaga zewnetrznego rezystora 10k do VCC.
     * Jesli uzywasz GPIO33 lub innego z pull-up: zmien na GPIO_PULLUP_ENABLE */
    gpio_config_t sw_cfg = {
        .pin_bit_mask = (1ULL << ENC_PIN_SW),
        .mode         = GPIO_MODE_INPUT,
        .pull_up_en   = GPIO_PULLUP_DISABLE,   /* brak dla GPIO34 */
        .pull_down_en = GPIO_PULLDOWN_DISABLE,
        .intr_type    = GPIO_INTR_DISABLE,
    };
    gpio_config(&sw_cfg);

    ESP_LOGI(TAG_ENC,
             "PCNT v2 OK — A=GPIO%d, B=GPIO%d, SW=GPIO%d | "
             "progi accel: x10@%d x100@%d x1000@%d imp/cykl",
             ENC_PIN_A, ENC_PIN_B, ENC_PIN_SW,
             ENC_ACCEL_THR1, ENC_ACCEL_THR2, ENC_ACCEL_THR3);
    return ESP_OK;
}
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

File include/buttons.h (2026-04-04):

/*===========================================================================
 *  buttons.h — Przyciski tact switch (ESP-IDF 5.x)
 *
 *  Przyciski (active LOW, INPUT_PULLUP):
 *    BTN_STEP_DN (GPIO27) — krok w dol
 *    BTN_STEP_UP (GPIO26) — krok w gore
 *    BTN_MEM     (GPIO25) — pamiec / YES w dialogu zapisu
 *    BTN_SAVE    (GPIO32) — zapis / NO w dialogu
 *    BTN_BAND    (GPIO33) — menu wyboru pasma (5. przycisk)
 *
 *  Logika czasowa:
 *    Krotkie nacisniecie (<500ms): akcja podstawowa
 *    Dlugie  (>=1000ms):           akcja alternatywna
 *    LOCK: BTN_STEP_DN + BTN_STEP_UP trzymane >= 1s jednoczesnie
 *===========================================================================*/
#pragma once
#include "esp_err.h"
#include <stdbool.h>

/* GPIO 5. przycisku BAND — zmien gdy znany */
#define BTN_BAND    33    /* wbudowany pull-up dostepny */

esp_err_t buttons_init(void);
void      buttons_task(void *arg);

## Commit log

2026-04-01 zmiany kalibracja, zmiana działania buttonów
2026-04-05 Dodanie env_devel, fix do pliku build.yml
    [main.c]
2026-04-06 Dodanie plików w Kicad 10.
    [VFO na esp32.kicad_pcb, VFO na esp32.kicad_sch]
2026-05-17 Dodano nowy plik README.md, poprawki w plikach projektu pcb w KICAD10.
    [VFO na esp32.kicad_sch]
2026-09-16 Poprawki w plikach schematu i pcb Kicada.
    [VFO na esp32.kicad_pcb, VFO na esp32.kicad_sch]
